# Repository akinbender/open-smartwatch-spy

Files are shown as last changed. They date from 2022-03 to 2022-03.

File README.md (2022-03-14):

# Open-Smartwatch Spy Edition beta
Based on the open source smartwatch project [Open-Smartwatch](https://open-smartwatch.github.io/) by [Paul's 3D Things](https://www.instagram.com/pauls_3d_things/?hl=en).
The rugged box is designed after this thingiverse [project](https://www.thingiverse.com/thing:4094861)
Check out my twitter [thread](https://twitter.com/AlternatifAkin/status/1460656525509369863) about the build.

## Must TODOs for v1.0 release
1. Fix button placements. (Buttons are in wrong order)
2. add female connector for battery, soldering is really unpleasent at that point of the assembly.
3. buy some other micro stepper motor such as [this geared one](https://www.ebay.de/itm/193621782182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) and a female [connector](https://www.aliexpress.com/item/4000012574440.html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) for it.
4. find schematic and footprint of the afformentioned female connector for the board, and order new pcb.
5. 3d design of the new motor & release mechanism
6. finish osw firmware extension for motor control (didn't check it in, not required at this point)
7. Fix rugged box design. (Current design cannot fit the straps and only has two dart holders) Also gotta fix my 3d printer to print another one.. 

## Optional TODOs
Check out Paul's instagram page, he has designed an awesome new watch. Ultimately and hopefully, I will also switch to the new board design.  I dont know which changes are going to be included when, but I have some plans.

1. switch micro-USB for [waterproof 4 pin connector](https://www.aliexpress.com/item/1005003687986489.html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)
2. switch buttons for some waterproof alternative, maybe seperate pcb touch buttons?
3. waterproof design with O-rings and stuff, don't really know how yet..
4. Induction Charging [option](https://www.aliexpress.com/item/1005003691851748.html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) 

## Notes
Currently there is a fully plastic test dart, and one that can be fashioned out of a M3 allen key. Depending on multiple build desicions, you can really end up hurting someone with the metal dart. This should go without saying, but I (and Paul) obviously do not accept any responsibility, I never do..

Also going to visit a local magic shop for guidance about trick darts. Magic is all about deception, most spygear too.. So maybe I might build some pyro, flash or smoke darts. Can also build an injector dart. I looked closely to my Covid vaccine injector, it can fit inside the chamber but there is no way that it can be useful.

###### I named the project because well, it's obvious right? But my aim was to build a self protection gear in the form of a daily wearable item for my sis and my mom. And lets face it, shooting darts is not the optimal solution for them. Long story short, after v1.0 release an alternative design with a gas canister instead of a dart shooter is also needed.

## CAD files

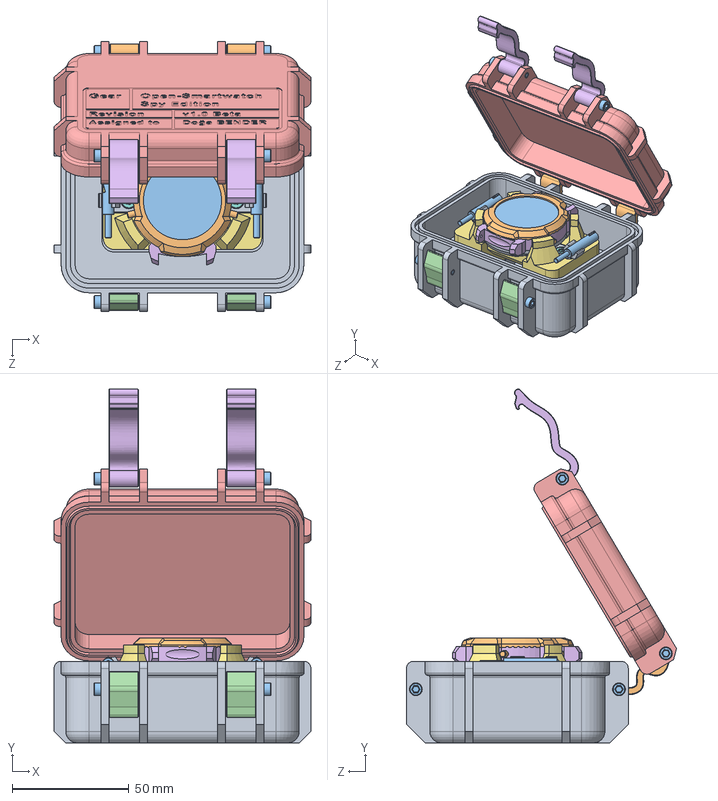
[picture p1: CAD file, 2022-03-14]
3d/prototype_box.SLDASM
110.0 x 151.6 x 115.6 mm
box_bottom
hinge x 2
M3x20 x 8
latch_cam x 2
box_top
latch_arm x 2
box_bottom_base
M4x12 x 2
box_bottom_payload_holder x 2
top_shell
top_glass
top_lcd
top_shell_inner
middle-shell
middle_osw_board
middle_payload_spring
middle_servo
middle_button x 4
middle_payload x 3
middle_servo_nut
middle_release_pin
middle_release_trigger
middle_release_spring
middle_release_cover
bottom_shell
bottom_battery
M1,6x10 x 4

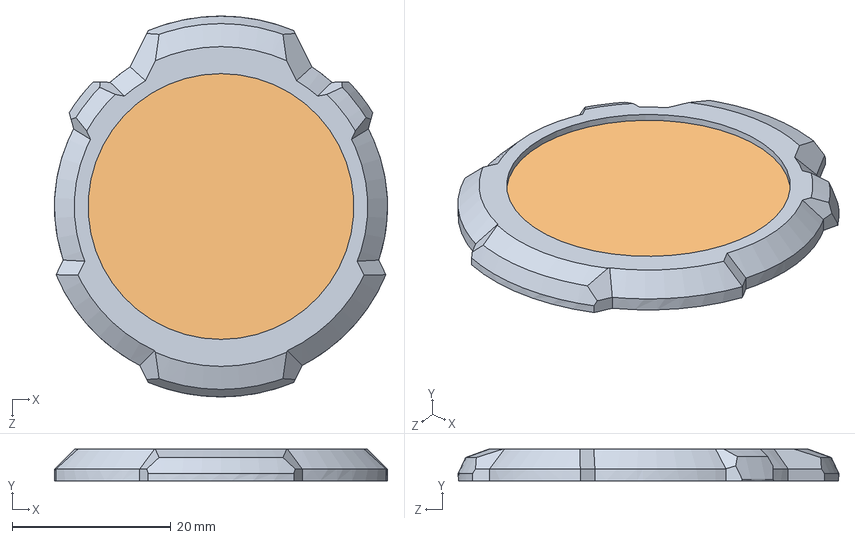
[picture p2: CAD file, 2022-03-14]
3d/spywatch/top_subassembly/top_subassembly.SLDASM
42.0 x 4.00 x 48.0 mm
top_shell
top_glass
top_lcd
top_shell_inner

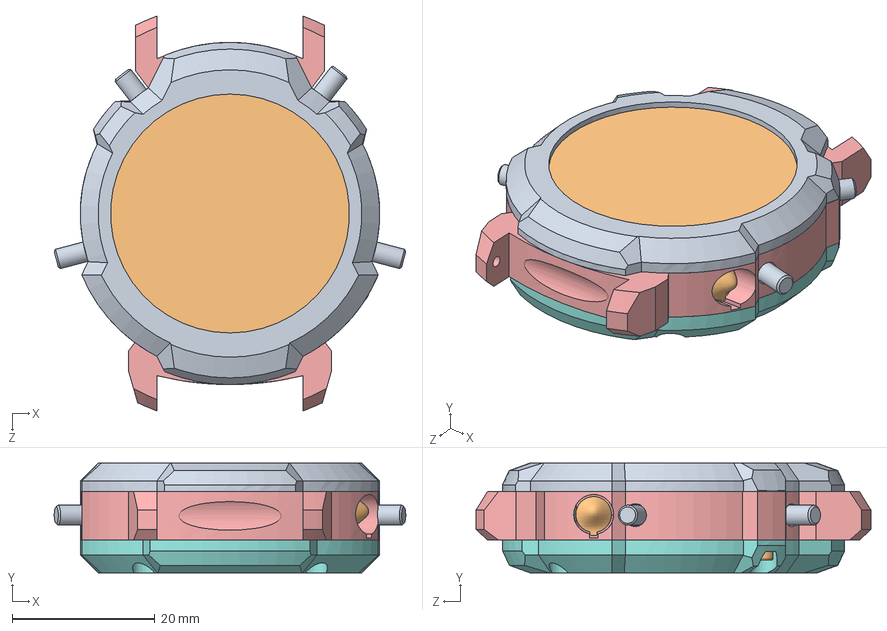
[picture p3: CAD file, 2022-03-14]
3d/spywatch/middle_subassembly_manual/osw_spy_manual.SLDASM
49.3 x 15.4 x 55.4 mm
top_shell
top_glass
top_lcd
top_shell_inner
middle_shell
middle_osw_board
middle_payload_spring
middle_servo
middle_button x 4
middle_payload_test
middle_servo_nut
middle_release_pin
middle_release_trigger
middle_release_spring
middle_release_cover
bottom_shell
bottom_battery
M1,6x10 x 4

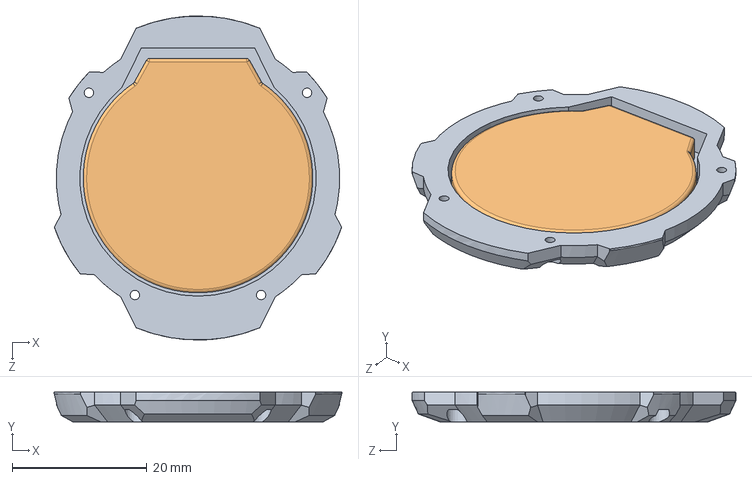
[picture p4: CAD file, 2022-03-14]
3d/spywatch/bottom_subassembly/bottom_subassembly.SLDASM
42.6 x 4.40 x 48.0 mm
bottom_shell
bottom_battery

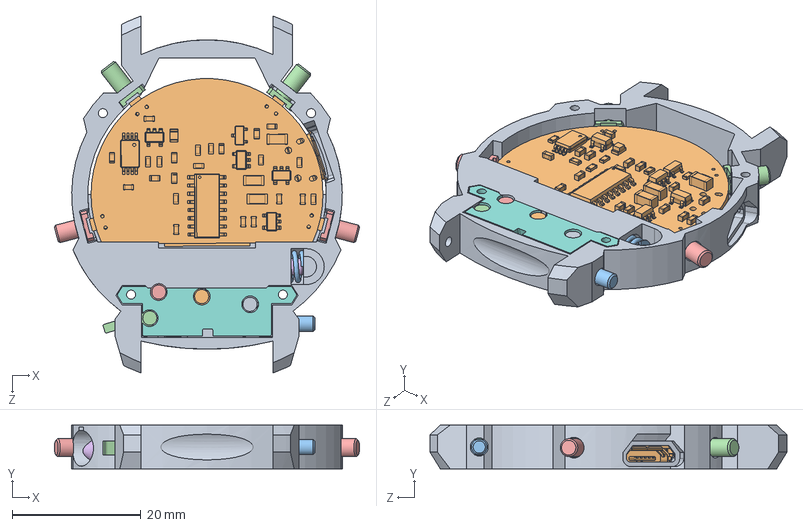
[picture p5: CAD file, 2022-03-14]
3d/spywatch/middle_subassembly_manual/middle_subassembly_manual.SLDASM
47.4 x 6.80 x 55.4 mm
middle_case
middle_osw_board
middle_payload_spring
middle_button_long x 2
middle_button_short x 2
middle_payload_test
middle_release_spring
middle_release_trigger_connector
middle_release_pin_connector
middle_release_trigger_button
middle_release_safety_pin
middle_release_pin

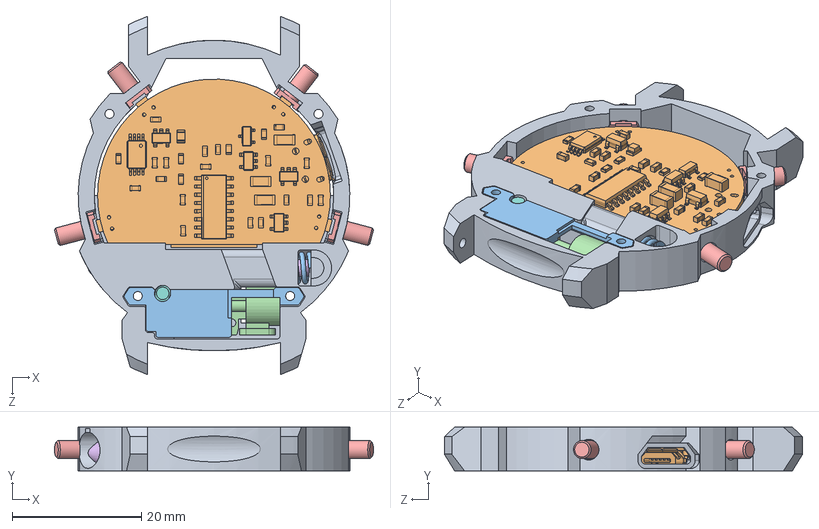
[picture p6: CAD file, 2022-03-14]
3d/spywatch/middle_subassembly_fail1/middle_subassembly_fail1.SLDASM
49.3 x 6.80 x 55.4 mm
middle_shell
middle_osw_board
middle_payload_spring
middle_servo
middle_button_long x 4
middle_payload_test
middle_servo_nut
middle_release_pin
middle_release_trigger
middle_release_spring
middle_release_cover

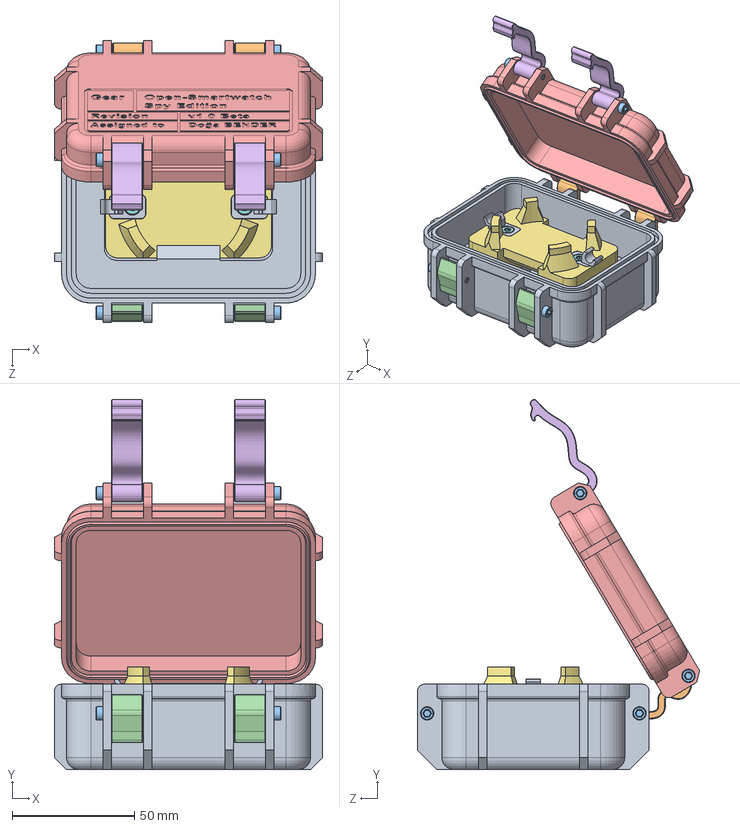
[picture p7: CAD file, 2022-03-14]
3d/rugged box/rugged box.SLDASM
110.0 x 151.6 x 115.6 mm
box_bottom
hinge x 2
M3x20 x 8
latch_cam x 2
box_top
latch_arm x 2
box_bottom_base
box_bottom_payload_holder x 2
M4x12

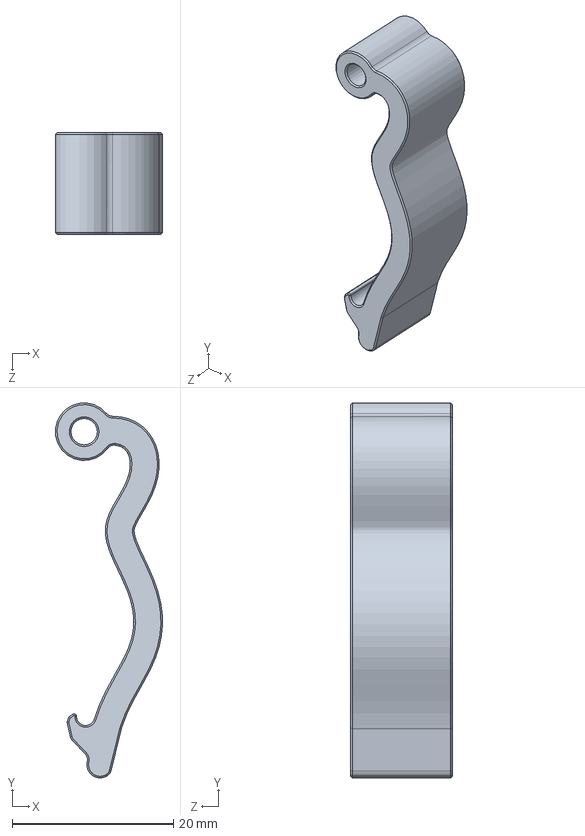
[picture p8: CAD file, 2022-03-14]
3d/rugged box/latch_arm.SLDPRT
13.3 x 46.5 x 12.6 mm

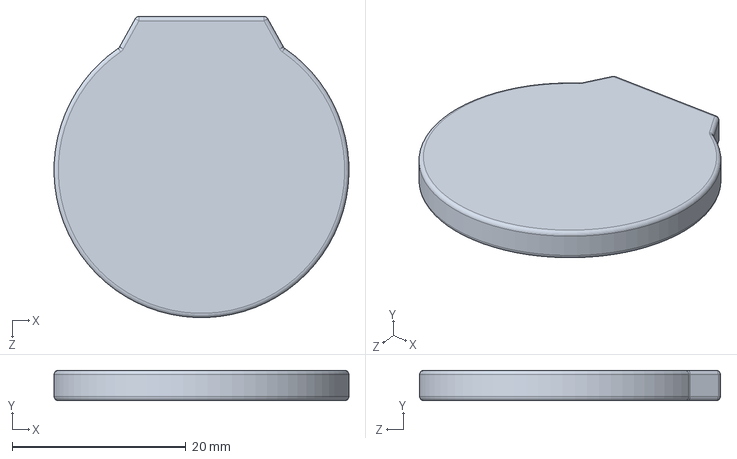
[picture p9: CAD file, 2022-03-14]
3d/spywatch/bottom_subassembly/bottom_battery.SLDPRT
34.0 x 3.50 x 34.7 mm

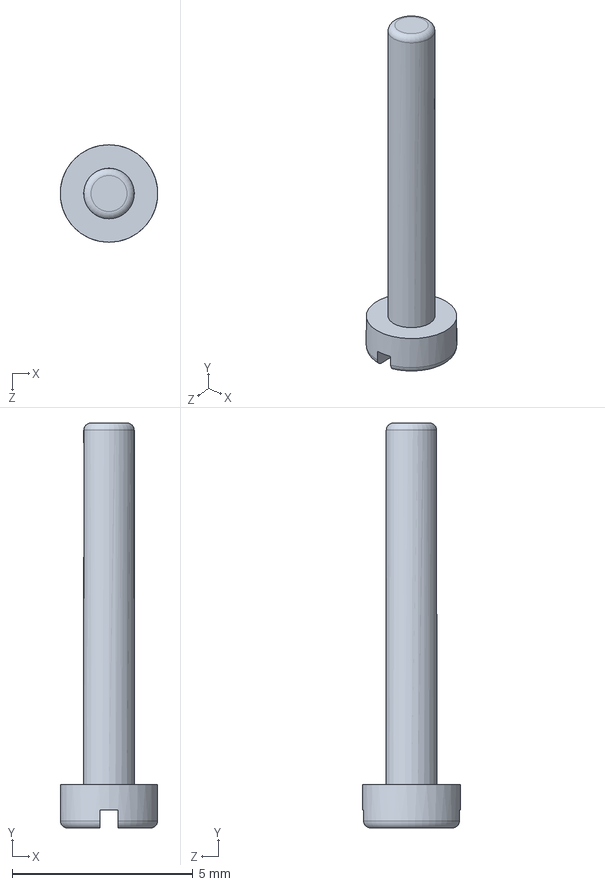
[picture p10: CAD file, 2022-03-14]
3d/spywatch/common/M1,6x10.SLDPRT
2.69 x 11.2 x 2.70 mm

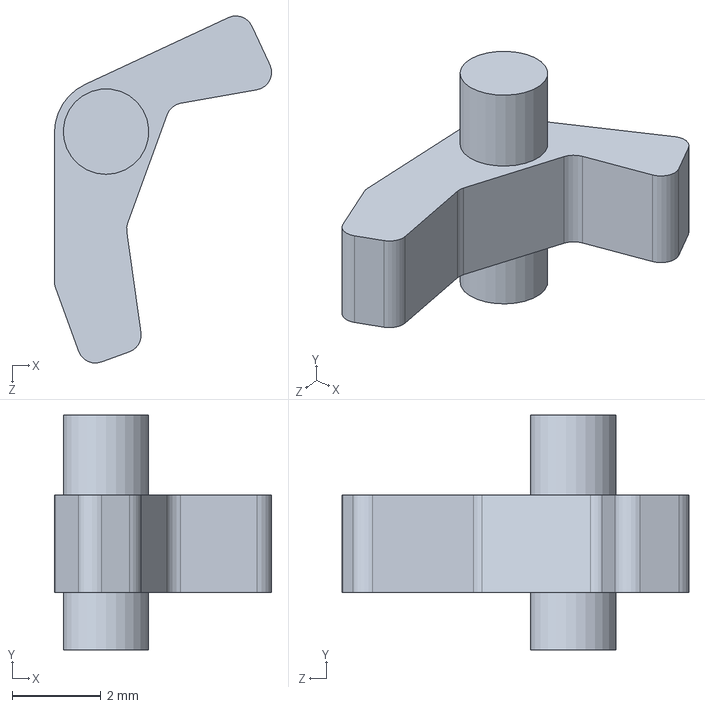
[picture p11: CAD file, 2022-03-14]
3d/spywatch/middle_subassembly_fail1/middle_release_pin.SLDPRT
4.90 x 5.30 x 7.83 mm

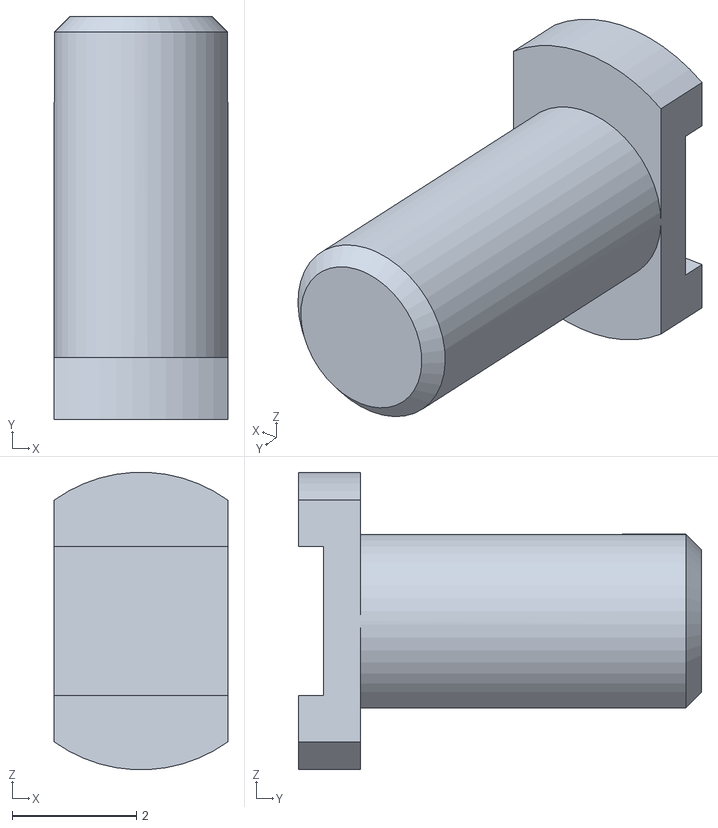
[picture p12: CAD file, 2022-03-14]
3d/spywatch/middle_subassembly_fail1/stl/middle_button.STL
2.80 x 6.50 x 4.79

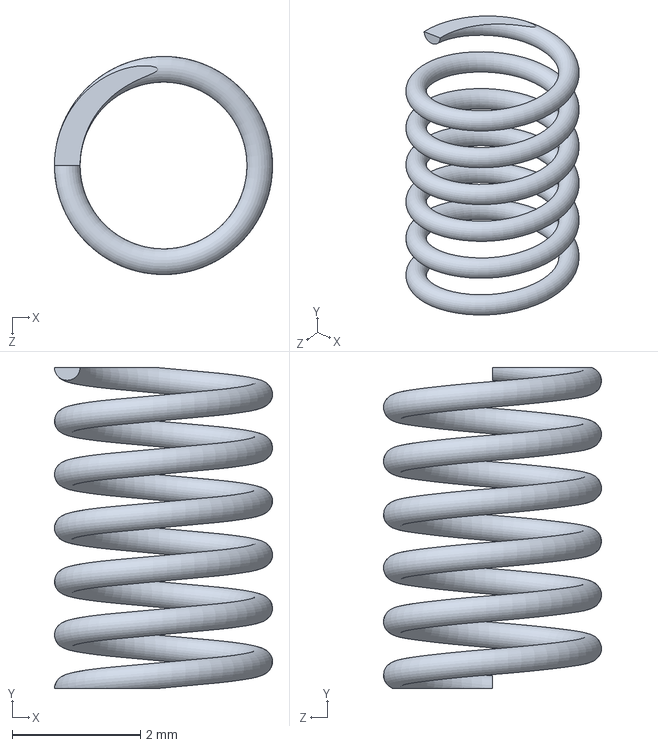
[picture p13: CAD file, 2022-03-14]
3d/spywatch/middle_subassembly_manual/middle_release_spring.SLDPRT
3.40 x 5.00 x 3.40 mm

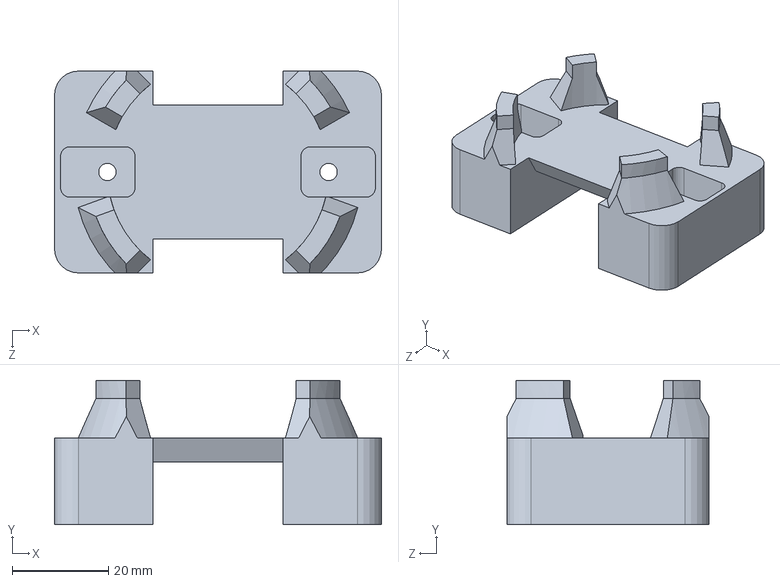
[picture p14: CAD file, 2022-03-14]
3d/rugged box/box_bottom_base.SLDPRT
68.0 x 30.0 x 42.0 mm

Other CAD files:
3d/spywatch/middle_subassembly_fail1/osw_spy_fail1.SLDASM
3d/rugged box/stls/latch arm v1.STL
3d/rugged box/stls/hinge v1.STL
3d/spywatch/bottom_subassembly/bottom_shell.SLDPRT
3d/rugged box/M3x20.SLDPRT
3d/rugged box/M4x12.SLDPRT
3d/rugged box/box bottom - old.SLDPRT
3d/rugged box/box_bottom.SLDPRT
3d/rugged box/box_bottom_payload_holder.SLDPRT
3d/rugged box/box_top.SLDPRT
3d/rugged box/hinge.SLDPRT
3d/rugged box/latch_cam.SLDPRT
3d/rugged box/stls/box top.STL
3d/rugged box/stls/box_bottom.STL
3d/rugged box/stls/box_bottom_base.STL
3d/rugged box/stls/box_bottom_payload_holder.STL
3d/rugged box/stls/latch cam v1.STL
3d/spywatch/bottom_subassembly/stl/bottom_shell.STL
3d/spywatch/common/middle_button_long.SLDPRT
3d/spywatch/common/middle_button_short.SLDPRT
3d/spywatch/common/middle_osw_board.SLDPRT
3d/spywatch/common/middle_payload_dart.SLDPRT
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

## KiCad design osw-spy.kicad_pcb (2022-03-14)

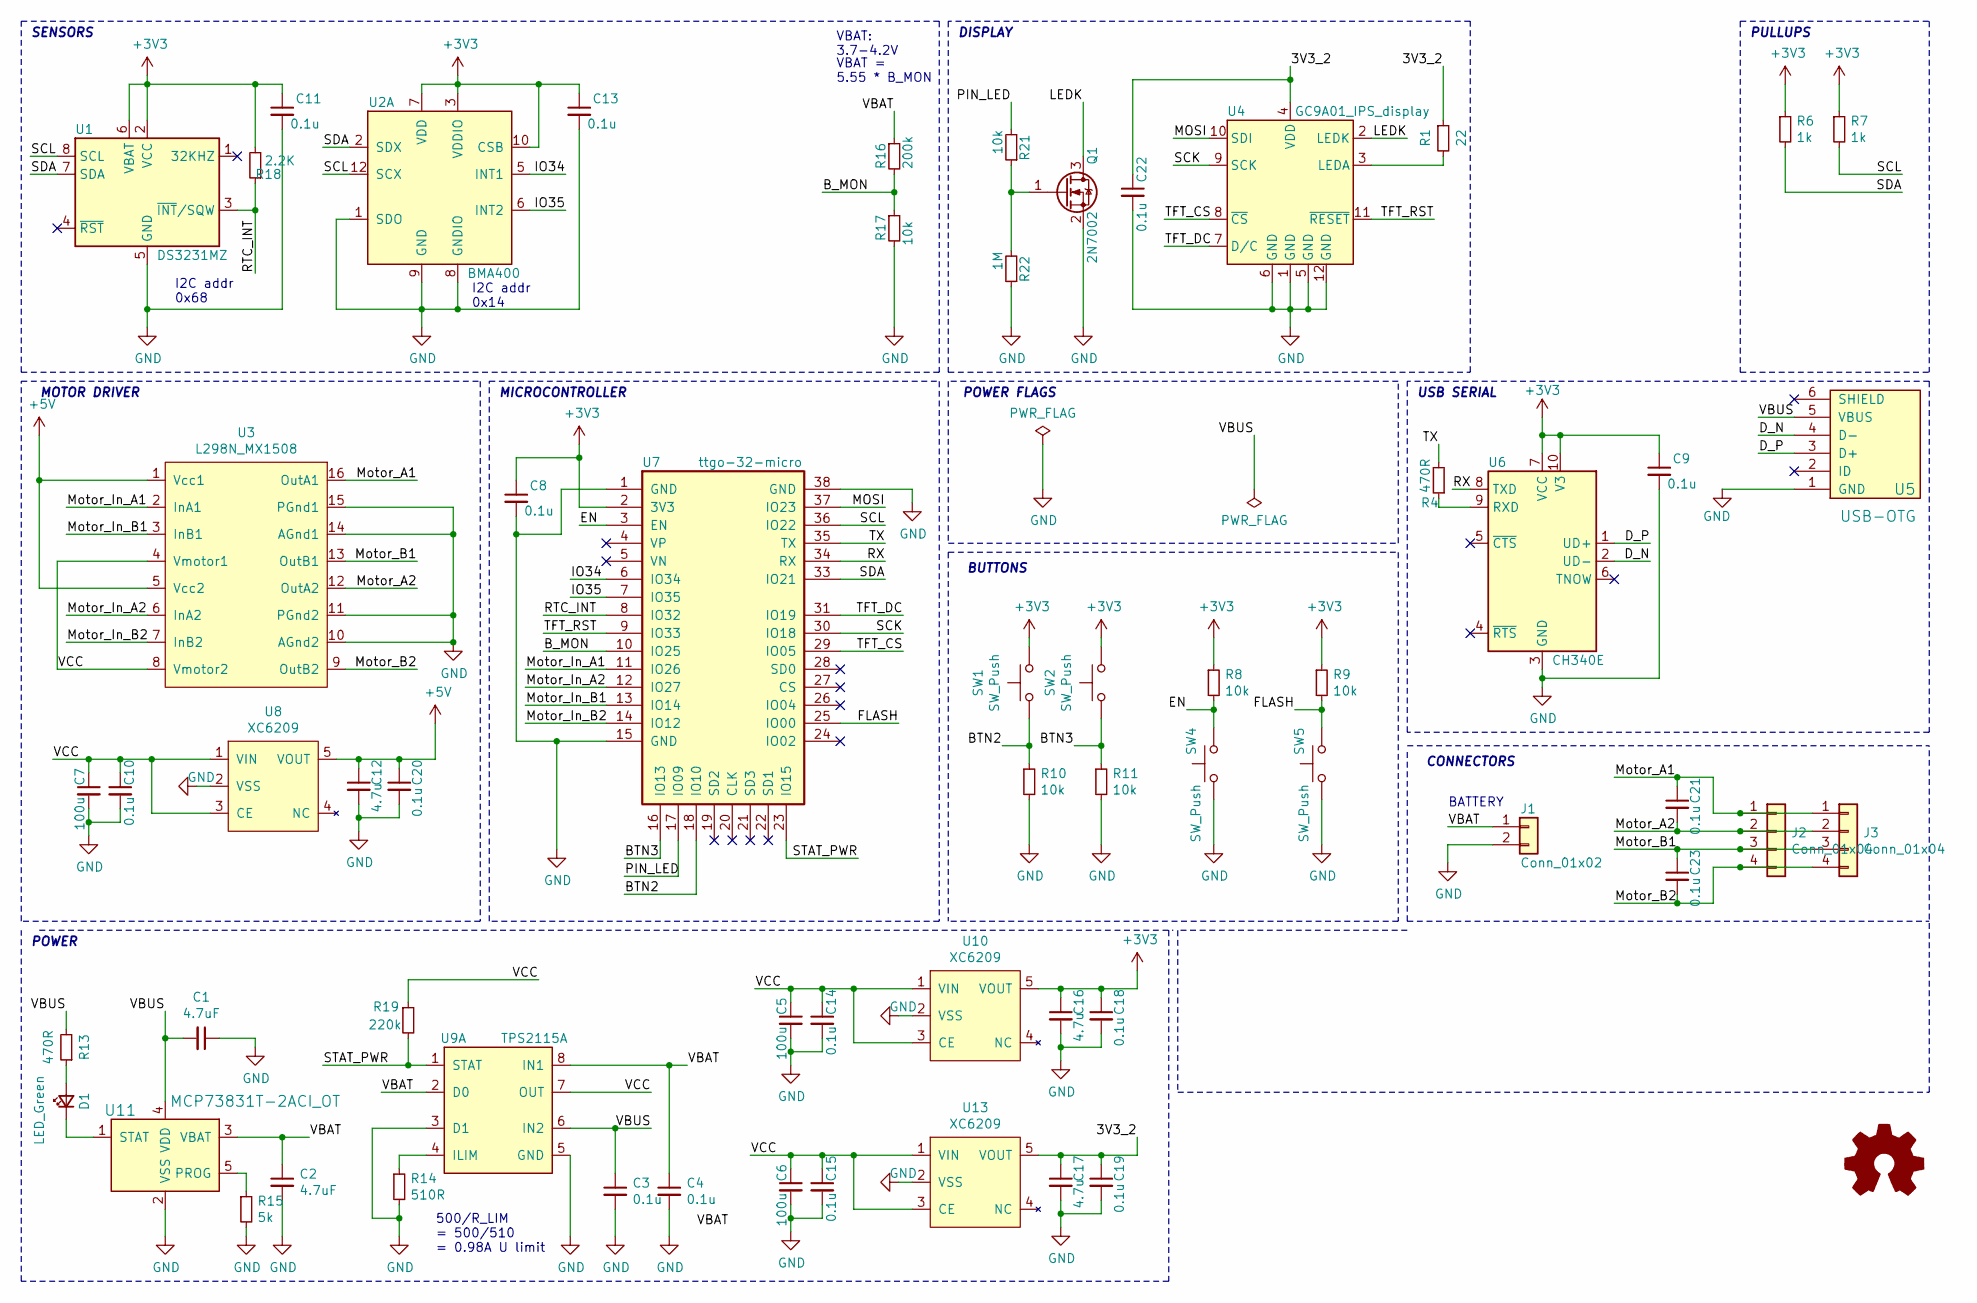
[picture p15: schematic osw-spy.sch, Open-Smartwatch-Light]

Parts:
C1, C2: 4.7uF; C_0603_1608Metric
C3, C4, C8, C9, C10, C11, C13, C14, C15, C18, C19, C20, C21, C22, C23: 0.1u; C_0603_1608Metric
C5, C6, C7: 100u; C_1206_3216Metric
C12, C16, C17: 4.7u; C_0603_1608Metric
D1: LED_Green; LED_0805_2012Metric
J1: Conn_01x02; PinHeader_1x02_P2.54mm_Vertical
J2, J3: Conn_01x04; PinHeader_1x04_P2.54mm_Vertical
Q1: 2N7002; SOT-23
R1: 22; R_0603_1608Metric
R4, R13: 470R; R_0603_1608Metric
R6, R7: 1k; R_0603_1608Metric
R8, R9, R10, R11, R17, R21: 10k; R_0603_1608Metric
R14: 510R; R_0603_1608Metric
R15: 5k; R_0603_1608Metric
R16: 200k; R_0603_1608Metric
R18: 2.2K; R_0603_1608Metric
R19: 220k; R_0603_1608Metric
R22: 1M; R_0603_1608Metric
SW1, SW2, SW4, SW5: SW_Push; button_side_smd
U1: DS3231MZ; SOIC-8_3.9x4.9mm_P1.27mm
U2: BMA400; LGA-12_2x2mm_P0.5mm; MPN BMA400; DigiKey_PN 828-1081-1-ND
U3: L298N_MX1508; SOP-16_3.9x9.9mm_P1.27mm
U4: GC9A01_IPS_display
U5: USB-OTG; USBmicro-B
U6: CH340E; MSOP-10_3x3mm_P0.5mm
U7: ttgo-32-micro
U8, U10, U13: XC6209; SOT-23-5
U9: TPS2115A; TSSOP-8_4.4x3mm_P0.65mm; MPN TPS2115APWR; DigiKey_PN 296-16940-1-ND
U11: MCP73831T-2ACI_OT; SOT-23-5; MPN MCP73831T-2ACI/OT; Digi-Key_PN MCP73831T-2ACI/OTCT-ND

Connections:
+3V3: C8.1, C9.1, C11.1, C13.1, C16.1, C18.1, R6.1, R7.1, R8.1, R9.1, R18.2, SW1.2, SW2.2, U1.2 (VCC), U1.6 (VBAT), U2.3 (VDDIO), U2.7 (VDD), U2.10 (CSB), U6.7 (VCC), U6.10 (V3), U7.2 (3V3), U10.5 (VOUT)
+5V: C12.1, C20.1, U3.1 (Vcc1), U3.5 (Vcc2), U8.5 (VOUT)
/3V3_2: C17.1, C19.1, C22.1, R1.1, U4.4 (VDD), U13.5 (VOUT)
/BTN2: R10.1, SW1.1, U7.18 (IO10)
/BTN3: R11.1, SW2.1, U7.16 (IO13)
/B_MON: R16.2, R17.1, U7.10 (IO25)
/D_N: U5.4 (D-), U6.2 (UD-)
/D_P: U5.3 (D+), U6.1 (UD+)
/EN: R8.2, SW4.2, U7.3 (EN)
/FLASH: R9.2, SW5.2, U7.25 (IO00)
/IO34: U2.5 (INT1), U7.6 (IO34)
/IO35: U2.6 (INT2), U7.7 (IO35)
/LEDK: Q1.3 (D), U4.2 (LEDK)
/MOSI: U4.10 (SDI), U7.37 (IO23)
/Motor_A1: C21.1, J2.1, J3.1, U3.16 (OutA1)
/Motor_A2: C21.2, J2.2, J3.2, U3.12 (OutA2)
/Motor_B1: C23.1, J2.3, J3.3, U3.13 (OutB1)
/Motor_B2: C23.2, J2.4, J3.4, U3.9 (OutB2)
/Motor_In_A1: U3.2 (InA1), U7.11 (IO26)
/Motor_In_A2: U3.6 (InA2), U7.12 (IO27)
/Motor_In_B1: U3.3 (InB1), U7.13 (IO14)
/Motor_In_B2: U3.7 (InB2), U7.14 (IO12)
/PIN_LED: R21.2, U7.17 (IO09)
/RTC_INT: R18.1, U1.3 (~INT~/SQW), U7.8 (IO32)
/RX: U6.8 (TXD), U7.34 (RX)
/SCK: U4.9 (SCK), U7.30 (IO18)
/SCL: R7.2, U1.8 (SCL), U2.12 (SCX), U7.36 (IO22)
/SDA: R6.2, U1.7 (SDA), U2.2 (SDX), U7.33 (IO21)
/STAT_PWR: R19.2, U7.23 (IO15), U9.1 (STAT)
/TFT_CS: U4.8 (~CS), U7.29 (IO05)
/TFT_DC: U4.7 (D/C), U7.31 (IO19)
/TFT_RST: U4.11 (~RESET), U7.9 (IO33)
/TX: R4.2, U7.35 (TX)
/VBAT: C2.1, C4.1, J1.1, R16.1, U9.2 (D0), U9.8 (IN1), U11.3 (VBAT)
/VBUS: C1.2, C3.1, R13.2, U5.5 (VBUS), U9.6 (IN2), U11.4 (VDD)
/VCC: C5.1, C6.1, C7.1, C10.1, C14.1, C15.1, R19.1, U3.4 (Vmotor1), U3.8 (Vmotor2), U8.1 (VIN), U8.3 (CE), U9.7 (OUT), U10.1 (VIN), U10.3 (CE), U13.1 (VIN), U13.3 (CE)
GND: C1.1, C2.2, C3.2, C4.2, C5.2, C6.2, C7.2, C8.2, C9.2, C10.2, C11.2, C12.2, C13.2, C14.2, C15.2, C16.2, C17.2, C18.2, C19.2, C20.2, C22.2, J1.2, Q1.2 (S), R10.2, R11.2, R14.2, R15.2, R17.2, R22.1, SW4.1, SW5.1, U1.5 (GND), U2.1 (SDO), U2.8 (GNDIO), U2.9 (GND), U3.10 (AGnd2), U3.11 (PGnd2), U3.14 (AGnd1), U3.15 (PGnd1), U4.1 (GND), U4.5 (GND), U4.6 (GND), U4.12 (GND), U5.1 (GND), U6.3 (GND), U7.1 (GND), U7.15 (GND), U7.38 (GND), U8.2 (VSS), U9.3 (D1), U9.5 (GND), U10.2 (VSS), U11.2 (VSS), U13.2 (VSS)
unnamed: D1.1 (K), U11.1 (STAT)
unnamed: D1.2 (A), R13.1
unnamed: Q1.1 (G), R21.1, R22.2
unnamed: R1.2, U4.3 (LEDA)
unnamed: R4.1, U6.9 (RXD)
unnamed: R14.1, U9.4 (ILIM)
unnamed: R15.1, U11.5 (PROG)

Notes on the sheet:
500/R_LIM = 500/510 = 0.98A U limit
SENSORS
POWER
DISPLAY
USB SERIAL
BUTTONS
PULLUPS
BATTERY
VBAT: 3.7-4.2V
VBAT = 5.55 * B_MON
MICROCONTROLLER
POWER FLAGS
I2C addr 0x68
I2C addr 0x14
CONNECTORS
MOTOR DRIVER

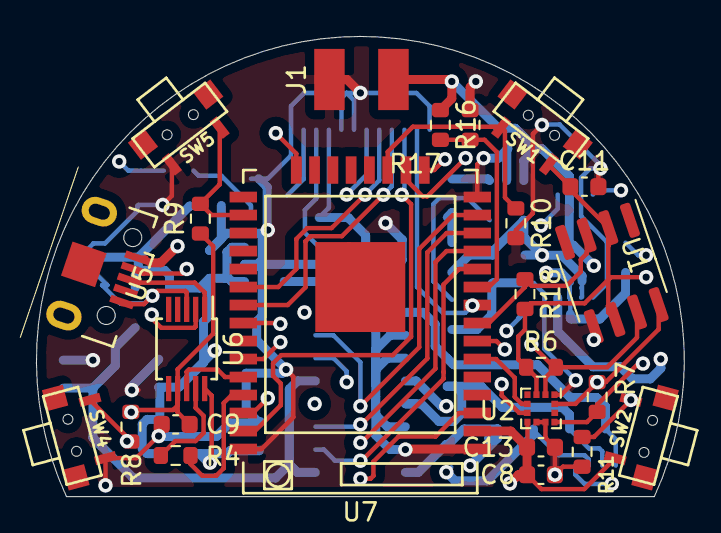
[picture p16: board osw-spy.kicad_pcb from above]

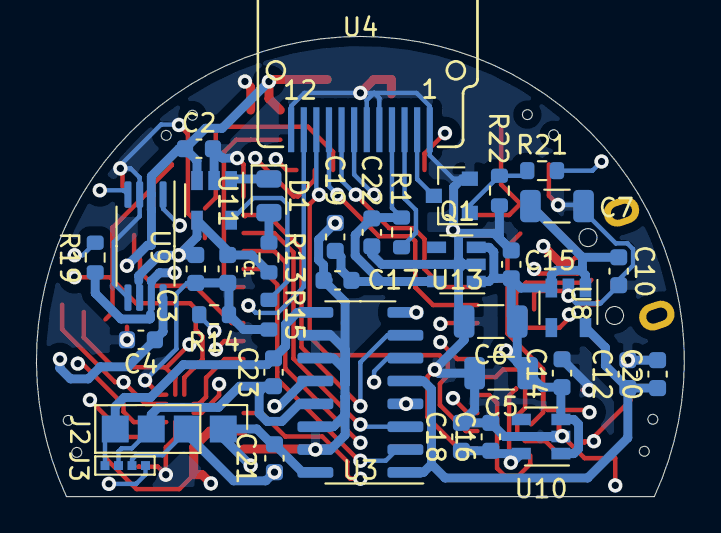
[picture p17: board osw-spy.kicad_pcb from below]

Board: 4 copper layers, 36.0 x 25.6 mm, 61 parts (37 on the bottom side), 44 nets.
